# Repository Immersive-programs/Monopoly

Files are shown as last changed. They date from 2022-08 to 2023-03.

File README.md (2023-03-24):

# OLD Monopoly

## Проект электронного терминала для игры Monopoly.

### Особенности:
- RFID карты (безконтакная оплата);
- Нет клавиатуры (Безконтактный ввод);
- Звуковая индикация;
- световая индикация.

### Компанентная база:
- Контроллер ESP32;
- Pcd8544 LCD дисплей;
- IR(nec) Приёмник сигнала;
- Mfrc522 Модуль для работы с RFID;
- Трёх цветный светодиод;
- Макетная плата под ESP.
- IR пульт "Car MP3 TZT"
- Зуммер 3.3V
- Понижаюший модуль 3.3V

### Зачем?:
- Терминал используется для замены бумажных денег на электронные карты, что значительно оптимизирует и ускоряет игровой процес. 

### Как играть?:
1. "Новая игра"
2. Поднести по очереди как минимум две карты с RFID
- Терминал будет отображать баланс каждого игрока(чтобы узнать какая карта привязана к счёту необходимо повторно поднести карту)
3. С помощью клавиш пульта ">||","+"/"-" выбрать необходимою операцию с балансом игроков  
4. "Подтвердить операцию картой"

### Дополнительные возможности:
- Востановить предыдущею игру (сохранение происходит после каждой банковской операции)
- Настройка:
  - Инвертировать пиксели экрана;
  - Отключение/Включение звуковой индикации; 
  - Выставление начаного счёта у игроков.
  
### Подключение компанентов: 
- Display:
  Название контакта дисплея | IO порт
  --- | ---
  BL | 13
  RST | 17
  CE | 32
  DC | 33
  DIR | 25
  CLK | 26

- RFID:
  Контакт | IO порт
  --- | ---
  SDA | 22
  SCK | 21
  MOSI | 19
  MI | 18
  SQI | 5
  RST | 16
  
- LEDS:
  Cветодтод | IO порт
  --- | ---
  R | 27
  G | 14
  B | 12
  
- Buzzer:
  Питание | IO порт
  --- | ---
  Power | 2

- IR:
  Выход с ИК приёмника | IO порт
  --- | ---
  DATA OUT | 15

### Если есть 3D принтер:
- В разделе "3D Models For Print" есть необходимые файлы для печати корпуса (Разработаны при помощи программы FreeCAD)
  - печать всех деталей проводилась с ширеной линий 0.2 mm и заполнением 100%
  - из-за не соверженства 3D модели "Monopoly-Крыша верх" пластик может немного потечь

### Реализация програмной части создовалась на MicroPython.

### Используемые библеотеки:
- micropython_ir -> https://github.com/peterhinch/micropython_ir
- micropython-mfrc522 -> https://github.com/cefn/micropython-mfrc522
- micropython-pcd8544 -> https://github.com/mcauser/micropython-pcd8544

### Деменстрация: 
- Фото:
  - 
- Видео:
  -  todo

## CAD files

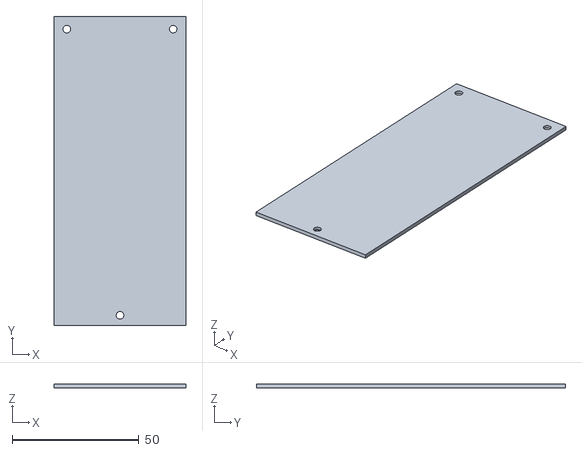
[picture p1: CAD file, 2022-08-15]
3D Models For Print/Monopoly-Крышка низ.stl
52.0 x 122.0 x 1.50

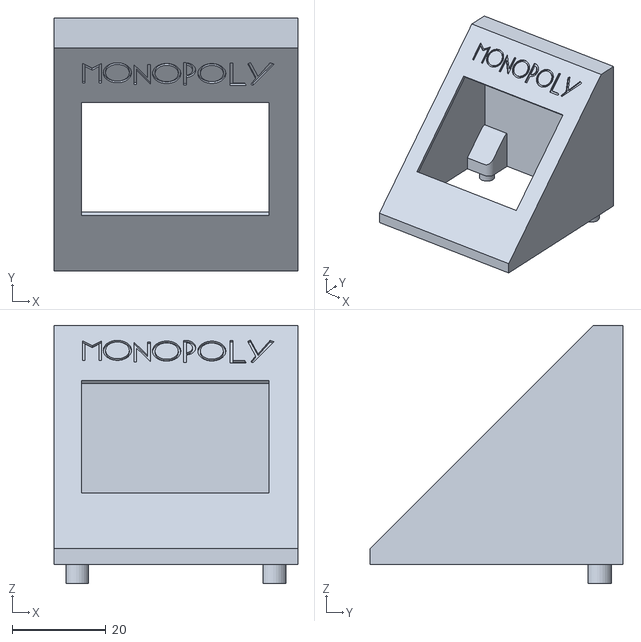
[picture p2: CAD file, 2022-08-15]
3D Models For Print/Monopoly-Крыша верх.stl
52.0 x 54.0 x 55.0

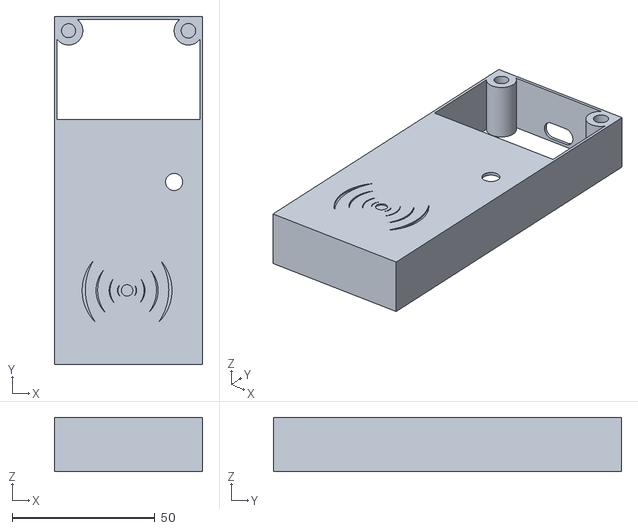
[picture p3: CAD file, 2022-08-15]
3D Models For Print/Monopoly-Основа.stl
52.0 x 122.0 x 19.0

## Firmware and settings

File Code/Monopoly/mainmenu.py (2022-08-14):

class mainmenu:
    def run(lcd, invert, select):
        tcolor = 1
        bcolor = 0
        if invert:
             tcolor = 0
             bcolor = 1
        lcd.fill(bcolor)
        lcd.text('МОНОПОЛИЯ:', -1, 0, tcolor)
        lcd.fill_rect(10,10,84,7,bcolor)
        lcd.text('НОВАЯ', -1, 10, tcolor)
        lcd.text('ИГРА', 40, 10, tcolor)
        
        lcd.text('В ', -1, 20, tcolor)
        lcd.text('О ', 6, 20, tcolor)
        lcd.text('С ', 13, 20, tcolor)
        lcd.text('Т ', 20, 20, tcolor)
        lcd.text('А ', 27, 20, tcolor)
        lcd.text('Н ', 34, 20, tcolor)
        lcd.text('О ', 41, 20, tcolor)
        lcd.text('В ', 48, 20, tcolor)
        lcd.text('И ', 55, 20, tcolor)
        lcd.text('Т ', 62, 20, tcolor)
        lcd.text('Ь ', 69, 20, tcolor)
        
        lcd.text('НАСТРОЙКИ', -1, 30, tcolor)
        lcd.text('О НАС', -1, 40, tcolor)
        
        lcd.text('НАСТРОЙКИ', -1, 30, tcolor)
        if select == 0:
            lcd.text('<', 76, 10, tcolor)
        elif select == 1:
            lcd.text('<', 76, 20, tcolor)
        elif select == 2:
            lcd.text('<', 76, 30, tcolor)
        elif select == 3:
            lcd.text('<', 76, 40, tcolor)
            
        lcd.show()

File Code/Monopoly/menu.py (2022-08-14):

from ir_rx.nec import NEC_8
from machine import Pin, Timer, PWM
from time import sleep
import gc
import mfrc522
class menu:
    
    mainselect = 0
    LCD = None
    tim = None
    menu = 0
    invert = False
    sselect = 0
    money = 1500
    sound = True
    players = [[],[]]
    mode = False;
    bfmoney = 0
    bfresult = 0
    idtr = '';
    rlp = 0
    glp = 0
    blp = 0
    
    def mainmenu():
        from mainmenu import mainmenu
        mainmenu.run(menu.LCD, invert=menu.invert, select=menu.mainselect)
        del mainmenu        
    def monopolymenu(i = -1):
        from monopoly import monopoly
        monopoly.run(menu.LCD, invert=menu.invert, select=i, players=menu.players)
        del monopoly
        if i >=0:
            menu.blp = PWM(Pin(12), freq=1000,duty_u16=42768)
            menu.rlp = PWM(Pin(27), freq=1000,duty_u16=0)
            menu.glp = PWM(Pin(14), freq=1000,duty_u16=0)
        else:
            menu.blp = PWM(Pin(12), freq=1000,duty_u16=12768)
            menu.rlp = PWM(Pin(27), freq=1000,duty_u16=0)
            menu.glp = PWM(Pin(14), freq=1000,duty_u16=0)
        menu.ir = NEC_8(Pin(15, Pin.IN), menu.IR)
    def settingsmenu():
        from settings import settings
        settings.run(menu.LCD, invert=menu.invert, select=menu.sselect, money = menu.money, sound = menu.sound)
        del settings 
    def paymenu():
        from paymenu import paymenu
        paymenu.run(menu.LCD, invert=menu.invert, select=menu.mainselect, mode = menu.mode)
        del paymenu
    def transfermenu():
        from transfer import transfer
        transfer.run(menu.LCD, invert=menu.invert, select=menu.mainselect)
        del transfer
        
    def IR(data, addr, ctrl):
        newdata = '{:02x}'.format(data)
        if menu.menu == 0:
            if newdata == '44':
                if menu.mainselect > 0:
                    menu.mainselect -= 1
                    menu.mainmenu()
            elif newdata == '40':
                if menu.mainselect < 3:
                    menu.mainselect += 1
                    menu.mainmenu()
            elif newdata == '43':
                if menu.mainselect == 0:
                    menu.startgame()
                elif menu.mainselect == 1:
                    menu.loadgame()
                    menu.startgame()
                elif menu.mainselect == 2:
                    menu.menu = 1
                    menu.settingsmenu()
                    gc.collect()
                elif menu.mainselect == 3:
                    menu.menu = 99
                    tcolor = 1
                    bcolor = 0
                    if menu.invert:
                        tcolor = 0
                        bcolor = 1
                    menu.LCD.fill(menu.invert)
                    menu.LCD.text('!СОЗДАТЕЛИ!', -1, 0, tcolor)
                    menu.LCD.text('КОМАНДА', 18, 10, tcolor)
                    menu.LCD.text('I', -2, 20, tcolor)
                    menu.LCD.text('m', 4, 20, tcolor)
                    menu.LCD.text('m', 12, 20, tcolor)
                    menu.LCD.text('e', 20, 20, tcolor)
                    menu.LCD.text('r', 27, 20, tcolor)
                    menu.LCD.text('s', 34, 20, tcolor)
                    menu.LCD.text('i', 39, 20, tcolor)
                    menu.LCD.text('v', 44, 20, tcolor)
                    menu.LCD.text('e', 51, 20, tcolor)
                    menu.LCD.text('C', 58, 20, tcolor)
                    menu.LCD.text('i', 63, 20, tcolor)
                    menu.LCD.text('t', 69, 20, tcolor)
                    menu.LCD.text('y', 76, 20, tcolor)
                    menu.LCD.text('НИКИТА И', 10, 30, tcolor)
                    menu.LCD.text('ДЕНИС', 24, 40, tcolor)
                    menu.LCD.show()
        elif menu.menu == 99:
            menu.menu = 0
            menu.mainmenu()
        elif menu.menu == 1:
            if newdata == '09':
                menu.menu = 0
                menu.mainmenu()
                gc.collect()
            elif newdata == '44':
                if menu.sselect > 0:
                    menu.sselect -= 1
                    menu.settingsmenu()
            elif newdata == '40':
                if menu.sselect < 2:
                    menu.sselect += 1
                    menu.settingsmenu()
            elif newdata == '43':
                if menu.sselect == 0:
                    if menu.invert:
                        menu.invert = False
                    else:
                        menu.invert = True
                    menu.savesettings()
                    menu.settingsmenu()
                if menu.sselect == 1:
                    if menu.sound:
                        menu.sound = False
                    else:
                        menu.sound = True
                    menu.savesettings()
                    menu.settingsmenu()
                if menu.sselect == 2:
                    menu.menu = 2
                    gc.collect()
        elif menu.menu == 2:
            bcolor = 0
            tcolor = 1
            if newdata == '09':
                if len(str(menu.money)) == 1:
                    menu.money = 0
                else:
                    menu.money = int(str(menu.money)[:-1])
            elif newdata == '0c':#1
                if len(str(menu.money)) < 4:    
                    if menu.money == 0:
                        menu.money = 1
                    else:
                        menu.money = int(str(menu.money)+'1')
            elif newdata == '18':#2
                if len(str(menu.money)) < 4:    
                    if menu.money == 0:
                        menu.money = 2
                    else:
                        menu.money = int(str(menu.money)+'2')
            elif newdata == '5e':#3
                if len(str(menu.money)) < 4:    
                    if menu.money == 0:
                        menu.money = 3
                    else:
                        menu.money = int(str(menu.money)+'3')
            elif newdata == '08':#4
                if len(str(menu.money)) < 4:    
                    if menu.money == 0:
                        menu.money = 4
                    else:
                        menu.money = int(str(menu.money)+'4')
            elif newdata == '1c':#5
                if len(str(menu.money)) < 4:    
                    if menu.money == 0:
                        menu.money = 5
                    else:
                        menu.money = int(str(menu.money)+'5')
            elif newdata == '5a':#6
                if len(str(menu.money)) < 4:    
                    if menu.money == 0:
                        menu.money = 6
                    else:
                        menu.money = int(str(menu.money)+'6')
            elif newdata == '42':#7
                if len(str(menu.money)) < 4:    
                    if menu.money == 0:
                        menu.money = 7
                    else:
                        menu.money = int(str(menu.money)+'7')
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
